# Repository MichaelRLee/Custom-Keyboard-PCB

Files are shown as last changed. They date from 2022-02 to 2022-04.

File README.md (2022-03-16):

# Lee Keyboard PCBs

Open source, hot-swappable board PCBs designed to be controlled by commonly available microcontroller boards (Pro Micro for the numpad, and Teensy LC, 3.2, etc. for the TKL).  These could easily be swapped out for any other board, but the qmk firmware would need to be modified for the specific controller.

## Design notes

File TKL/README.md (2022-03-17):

# tenleeless

tenleeless

<table>
<th colspan=2 style="text-align:center">Firmware</th>
<tr>
<td><a href="https://github.com/MichaelRLee/qmk_firmware/tree/tenkeyless/keyboards/finz/tenleeless">QMK</a></td>
<td><a href="">Vial</a></td>
</tr>
</table>

A hotswappable tenkeyless board, designed  with using a Teensy 3.2 as the controller.  Other controller boards with the same pinout (like the Teensy LC), should be usable, or any board with enough pins if not using pin headers (though adjustments to the QMK firmware would be needed).

### Design notes

The gap between the function keys and the alphanumeric cluster, as well as between the cluster and the nav keys, is 0.25u.  The spacebar stabalizer is the only one that has been flipped (wire north of the switch).  Any non-tray mounted mounting plate that fits the above should work with this PCB, though it was designed using a kbd8x plate as reference.

The board was is limted to a 7u space bar (1.5u ctrl/alt keys and 1u win keys, no fn/menu key), as well as a stepped caps lock.

As the microcontroller is located above the left arrow key, you may want to use a daughterboard (or female USB port).

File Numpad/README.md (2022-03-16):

# leepad

leepad

<table>
<th colspan=2 style="text-align:center">Firmware</th>
<tr>
<td><a href="https://github.com/MichaelRLee/qmk_firmware/tree/numpad/keyboards/finz/leepad">QMK</a></td>
<td><a href="https://github.com/MichaelRLee/vial-qmk/tree/numpad/keyboards/finz/leepad">Vial</a></td>
</tr>
</table>

A hotswappable numpad with extra macro keys.  Designed with the intention of using a Pro Micro as the controller, though the the spacing between the two PTH collumns do not reflect this.  What that means is that wires will have to be used in place of at least one row of pin headers.  The rational for this is to allow flexibility when mounting the Pro Micro (left or right side, or relocate the Pro Micro entirely).

Files (kicad and gerber) for a mounting plate are also included, which can easily be manufactured at the same time as the PCB.  For reference, the spacing between the macro keys and the rest of the keybaord is 0.25u, and all stabalizers have the wires facing inwards.

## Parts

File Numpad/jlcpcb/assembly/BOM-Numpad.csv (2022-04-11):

Comment | Designator | Footprint | LCSC
R_Small | R1 | R_Axial_DIN0207_L6.3mm_D2.5mm_P10.16mm_Horizontal
1N4148 | D16 | D_DO-34_SOD68_P7.62mm_Horizontal
1N4148 | D13 | D_DO-34_SOD68_P7.62mm_Horizontal
1N4148 | D8 | D_DO-34_SOD68_P7.62mm_Horizontal
1N4148 | D18 | D_DO-34_SOD68_P7.62mm_Horizontal
1N4148 | D17 | D_DO-34_SOD68_P7.62mm_Horizontal
1N4148 | D10 | D_DO-34_SOD68_P7.62mm_Horizontal
1N4148 | D5 | D_DO-34_SOD68_P7.62mm_Horizontal
1N4148 | D2 | D_DO-34_SOD68_P7.62mm_Horizontal
1N4148 | D3 | D_DO-34_SOD68_P7.62mm_Horizontal
1N4148 | D11 | D_DO-34_SOD68_P7.62mm_Horizontal
1N4148 | D15 | D_DO-34_SOD68_P7.62mm_Horizontal
1N4148 | D4 | D_DO-34_SOD68_P7.62mm_Horizontal
1N4148 | D19 | D_DO-34_SOD68_P7.62mm_Horizontal
1N4148 | D21 | D_DO-34_SOD68_P7.62mm_Horizontal
1N4148 | D6 | D_DO-34_SOD68_P7.62mm_Horizontal
1N4148 | D20 | D_DO-34_SOD68_P7.62mm_Horizontal
1N4148 | D12 | D_DO-34_SOD68_P7.62mm_Horizontal
1N4148 | D1 | D_DO-34_SOD68_P7.62mm_Horizontal
1N4148 | D9 | D_DO-34_SOD68_P7.62mm_Horizontal
1N4148 | D14 | D_DO-34_SOD68_P7.62mm_Horizontal
1N4148 | D7 | D_DO-34_SOD68_P7.62mm_Horizontal

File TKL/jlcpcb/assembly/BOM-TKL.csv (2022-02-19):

Comment | Designator | Footprint | LCSC
Tab | MX33 | MXOnly-1.5U-Hotswap-Antishear
; | MX59 | MXOnly-1U-Hotswap-Antishear
R_Alt | MX81 | MXOnly-1.5U-Hotswap-Antishear
v | MX68 | MXOnly-1U-Hotswap-Antishear
Insert | MX31 | MXOnly-1U-Hotswap-Antishear
m | MX71 | MXOnly-1U-Hotswap-Antishear
F10 | MX11 | MXOnly-1U-Hotswap-Antishear
Page Down | MX76 | MXOnly-1U-Hotswap-Antishear
F5 | MX6 | MXOnly-1U-Hotswap-Antishear
Enter | MX61 | MXOnly-2.25U-Hotswap-Antishear
r | MX37 | MXOnly-1U-Hotswap-Antishear
x | MX66 | MXOnly-1U-Hotswap-Antishear
, | MX72 | MXOnly-1U-Hotswap-Antishear
L_Alt | MX79 | MXOnly-1.5U-Hotswap-Antishear
9 | MX26 | MXOnly-1U-Hotswap-Antishear
5 | MX22 | MXOnly-1U-Hotswap-Antishear
L_Shift | MX64 | MXOnly-2.25U-Hotswap-Antishear
- | MX28 | MXOnly-1U-Hotswap-Antishear
0 | MX27 | MXOnly-1U-Hotswap-Antishear
= | MX29 | MXOnly-1U-Hotswap-Antishear
z | MX65 | MXOnly-1U-Hotswap-Antishear
g | MX54 | MXOnly-1U-Hotswap-Antishear
o | MX42 | MXOnly-1U-Hotswap-Antishear
Pause | MX16 | MXOnly-1U-Hotswap-Antishear
F4 | MX5 | MXOnly-1U-Hotswap-Antishear
7 | MX24 | MXOnly-1U-Hotswap-Antishear
j | MX56 | MXOnly-1U-Hotswap-Antishear
F11 | MX12 | MXOnly-1U-Hotswap-Antishear
Backspace | MX30 | MXOnly-2U-Hotswap-Antishear
h | MX55 | MXOnly-1U-Hotswap-Antishear
. | MX73 | MXOnly-1U-Hotswap-Antishear
End | MX48 | MXOnly-1U-Hotswap-Antishear
Print Screen | MX14 | MXOnly-1U-Hotswap-Antishear
q | MX34 | MXOnly-1U-Hotswap-Antishear
3 | MX20 | MXOnly-1U-Hotswap-Antishear
p | MX43 | MXOnly-1U-Hotswap-Antishear
c | MX67 | MXOnly-1U-Hotswap-Antishear
n | MX70 | MXOnly-1U-Hotswap-Antishear
F8 | MX9 | MXOnly-1U-Hotswap-Antishear
] | MX45 | MXOnly-1U-Hotswap-Antishear
Page Up | MX32 | MXOnly-1U-Hotswap-Antishear
y | MX39 | MXOnly-1U-Hotswap-Antishear
F2 | MX3 | MXOnly-1U-Hotswap-Antishear
i | MX41 | MXOnly-1U-Hotswap-Antishear
a | MX50 | MXOnly-1U-Hotswap-Antishear
F1 | MX2 | MXOnly-1U-Hotswap-Antishear
\ | MX46 | MXOnly-1.5U-Hotswap-Antishear
Teensy3.2 | U1 | Teensy30_31_32_LC
L_Ctrl | MX77 | MXOnly-1.5U-Hotswap-Antishear
2 | MX19 | MXOnly-1U-Hotswap-Antishear
L_Win | MX78 | MXOnly-1U-Hotswap-Antishear
Scroll Lock | MX15 | MXOnly-1U-Hotswap-Antishear-LED
[ | MX44 | MXOnly-1U-Hotswap-Antishear
R_Shift | MX75 | MXOnly-2.75U-Hotswap-Antishear
Down | MX85 | MXOnly-1U-Hotswap-Antishear
F6 | MX7 | MXOnly-1U-Hotswap-Antishear
' | MX60 | MXOnly-1U-Hotswap-Antishear
u | MX40 | MXOnly-1U-Hotswap-Antishear
Left | MX84 | MXOnly-1U-Hotswap-Antishear
4 | MX21 | MXOnly-1U-Hotswap-Antishear
Space | MX80 | MXOnly-7U-Hotswap-Antishear-ReversedStabilizers
Caps Lock | MX49 | MXOnly-1U-Hotswap-Antishear-LED
F3 | MX4 | MXOnly-1U-Hotswap-Antishear
Esc | MX1 | MXOnly-1U-Hotswap-Antishear
6 | MX23 | MXOnly-1U-Hotswap-Antishear
F12 | MX13 | MXOnly-1U-Hotswap-Antishear
t | MX38 | MXOnly-1U-Hotswap-Antishear
Home | MX63 | MXOnly-1U-Hotswap-Antishear
R_Ctrl | MX83 | MXOnly-1.5U-Hotswap-Antishear
F7 | MX8 | MXOnly-1U-Hotswap-Antishear
Delete | MX47 | MXOnly-1U-Hotswap-Antishear
k | MX57 | MXOnly-1U-Hotswap-Antishear
R_Win | MX82 | MXOnly-1U-Hotswap-Antishear
F9 | MX10 | MXOnly-1U-Hotswap-Antishear
Up | MX62 | MXOnly-1U-Hotswap-Antishear
e | MX36 | MXOnly-1U-Hotswap-Antishear
d | MX52 | MXOnly-1U-Hotswap-Antishear
8 | MX25 | MXOnly-1U-Hotswap-Antishear
w | MX35 | MXOnly-1U-Hotswap-Antishear
` | MX17 | MXOnly-1U-Hotswap-Antishear
b | MX69 | MXOnly-1U-Hotswap-Antishear
Right | MX86 | MXOnly-1U-Hotswap-Antishear
/ | MX74 | MXOnly-1U-Hotswap-Antishear
1 | MX18 | MXOnly-1U-Hotswap-Antishear
l | MX58 | MXOnly-1U-Hotswap-Antishear
s | MX51 | MXOnly-1U-Hotswap-Antishear
f | MX53 | MXOnly-1U-Hotswap-Antishear
1N4148 | D39 | D_DO-35_SOD27_P7.62mm_Horizontal
1N4148 | D36 | D_DO-35_SOD27_P7.62mm_Horizontal
1N4148 | D24 | D_DO-35_SOD27_P7.62mm_Horizontal
1N4148 | D73 | D_DO-35_SOD27_P7.62mm_Horizontal
1N4148 | D41 | D_DO-35_SOD27_P7.62mm_Horizontal
1N4148 | D7 | D_DO-35_SOD27_P7.62mm_Horizontal
1N4148 | D28 | D_DO-35_SOD27_P7.62mm_Horizontal
1N4148 | D57 | D_DO-35_SOD27_P7.62mm_Horizontal
1N4148 | D21 | D_DO-35_SOD27_P7.62mm_Horizontal
1N4148 | D75 | D_DO-35_SOD27_P7.62mm_Horizontal
1N4148 | D72 | D_DO-35_SOD27_P7.62mm_Horizontal
1N4148 | D37 | D_DO-35_SOD27_P7.62mm_Horizontal
1N4148 | D60 | D_DO-35_SOD27_P7.62mm_Horizontal
1N4148 | D27 | D_DO-35_SOD27_P7.62mm_Horizontal
1N4148 | D77 | D_DO-35_SOD27_P7.62mm_Horizontal
1N4148 | D5 | D_DO-35_SOD27_P7.62mm_Horizontal
1N4148 | D46 | D_DO-35_SOD27_P7.62mm_Horizontal
1N4148 | D86 | D_DO-35_SOD27_P7.62mm_Horizontal
1N4148 | D64 | D_DO-35_SOD27_P7.62mm_Horizontal
1N4148 | D44 | D_DO-35_SOD27_P7.62mm_Horizontal
1N4148 | D59 | D_DO-35_SOD27_P7.62mm_Horizontal
1N4148 | D1 | D_DO-35_SOD27_P7.62mm_Horizontal
1N4148 | D30 | D_DO-35_SOD27_P7.62mm_Horizontal
1N4148 | D61 | D_DO-35_SOD27_P7.62mm_Horizontal
1N4148 | D19 | D_DO-35_SOD27_P7.62mm_Horizontal
1N4148 | D25 | D_DO-35_SOD27_P7.62mm_Horizontal
1N4148 | D3 | D_DO-35_SOD27_P7.62mm_Horizontal
1N4148 | D49 | D_DO-35_SOD27_P7.62mm_Horizontal
1N4148 | D81 | D_DO-35_SOD27_P7.62mm_Horizontal
1N4148 | D14 | D_DO-35_SOD27_P7.62mm_Horizontal
1N4148 | D63 | D_DO-35_SOD27_P7.62mm_Horizontal
1N4148 | D78 | D_DO-35_SOD27_P7.62mm_Horizontal
1N4148 | D9 | D_DO-35_SOD27_P7.62mm_Horizontal
1N4148 | D79 | D_DO-35_SOD27_P7.62mm_Horizontal
1N4148 | D12 | D_DO-35_SOD27_P7.62mm_Horizontal
1N4148 | D43 | D_DO-35_SOD27_P7.62mm_Horizontal
1N4148 | D82 | D_DO-35_SOD27_P7.62mm_Horizontal
1N4148 | D48 | D_DO-35_SOD27_P7.62mm_Horizontal
1N4148 | D53 | D_DO-35_SOD27_P7.62mm_Horizontal
1N4148 | D40 | D_DO-35_SOD27_P7.62mm_Horizontal
1N4148 | D31 | D_DO-35_SOD27_P7.62mm_Horizontal
1N4148 | D35 | D_DO-35_SOD27_P7.62mm_Horizontal
1N4148 | D45 | D_DO-35_SOD27_P7.62mm_Horizontal
1N4148 | D68 | D_DO-35_SOD27_P7.62mm_Horizontal
1N4148 | D29 | D_DO-35_SOD27_P7.62mm_Horizontal
1N4148 | D54 | D_DO-35_SOD27_P7.62mm_Horizontal
1N4148 | D65 | D_DO-35_SOD27_P7.62mm_Horizontal
1N4148 | D33 | D_DO-35_SOD27_P7.62mm_Horizontal
1N4148 | D51 | D_DO-35_SOD27_P7.62mm_Horizontal
1N4148 | D70 | D_DO-35_SOD27_P7.62mm_Horizontal
1N4148 | D11 | D_DO-35_SOD27_P7.62mm_Horizontal
1N4148 | D6 | D_DO-35_SOD27_P7.62mm_Horizontal
1N4148 | D69 | D_DO-35_SOD27_P7.62mm_Horizontal
1N4148 | D52 | D_DO-35_SOD27_P7.62mm_Horizontal
1N4148 | D67 | D_DO-35_SOD27_P7.62mm_Horizontal
1N4148 | D32 | D_DO-35_SOD27_P7.62mm_Horizontal
1N4148 | D18 | D_DO-35_SOD27_P7.62mm_Horizontal
1N4148 | D34 | D_DO-35_SOD27_P7.62mm_Horizontal
1N4148 | D47 | D_DO-35_SOD27_P7.62mm_Horizontal
1N4148 | D62 | D_DO-35_SOD27_P7.62mm_Horizontal
1N4148 | D16 | D_DO-35_SOD27_P7.62mm_Horizontal
1N4148 | D85 | D_DO-35_SOD27_P7.62mm_Horizontal
1N4148 | D15 | D_DO-35_SOD27_P7.62mm_Horizontal
1N4148 | D20 | D_DO-35_SOD27_P7.62mm_Horizontal
1N4148 | D83 | D_DO-35_SOD27_P7.62mm_Horizontal
1N4148 | D10 | D_DO-35_SOD27_P7.62mm_Horizontal
1N4148 | D76 | D_DO-35_SOD27_P7.62mm_Horizontal
1N4148 | D50 | D_DO-35_SOD27_P7.62mm_Horizontal
R_Small | R1 | R_Axial_DIN0207_L6.3mm_D2.5mm_P7.62mm_Horizontal
1N4148 | D58 | D_DO-35_SOD27_P7.62mm_Horizontal
1N4148 | D13 | D_DO-35_SOD27_P7.62mm_Horizontal
1N4148 | D80 | D_DO-35_SOD27_P7.62mm_Horizontal
1N4148 | D4 | D_DO-35_SOD27_P7.62mm_Horizontal
1N4148 | D8 | D_DO-35_SOD27_P7.62mm_Horizontal
1N4148 | D55 | D_DO-35_SOD27_P7.62mm_Horizontal
1N4148 | D38 | D_DO-35_SOD27_P7.62mm_Horizontal
1N4148 | D56 | D_DO-35_SOD27_P7.62mm_Horizontal
1N4148 | D42 | D_DO-35_SOD27_P7.62mm_Horizontal
1N4148 | D2 | D_DO-35_SOD27_P7.62mm_Horizontal
1N4148 | D74 | D_DO-35_SOD27_P7.62mm_Horizontal
1N4148 | D84 | D_DO-35_SOD27_P7.62mm_Horizontal
R_Small | R2 | R_Axial_DIN0207_L6.3mm_D2.5mm_P7.62mm_Horizontal
1N4148 | D66 | D_DO-35_SOD27_P7.62mm_Horizontal
1N4148 | D17 | D_DO-35_SOD27_P7.62mm_Horizontal
1N4148 | D22 | D_DO-35_SOD27_P7.62mm_Horizontal
1N4148 | D26 | D_DO-35_SOD27_P7.62mm_Horizontal
1N4148 | D71 | D_DO-35_SOD27_P7.62mm_Horizontal
1N4148 | D23 | D_DO-35_SOD27_P7.62mm_Horizontal

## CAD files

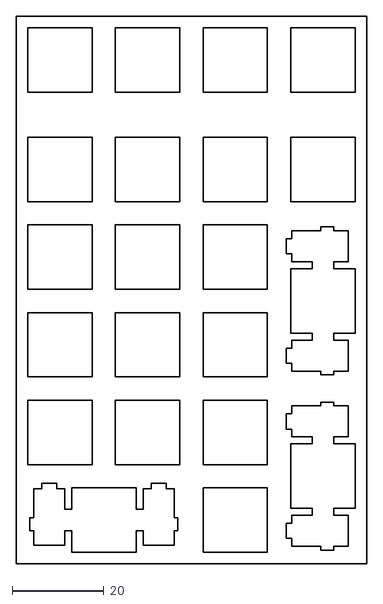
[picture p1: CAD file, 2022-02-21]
Numpad/plate/numpad-plate.dxf
76.2 x 119.1

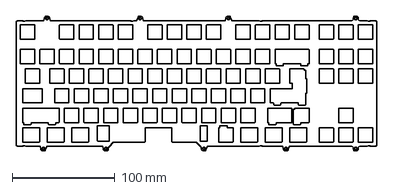
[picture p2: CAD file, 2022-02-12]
TKL/KBD8X-MKII-Plate-Simplified.dxf
350.6 x 130.7 mm

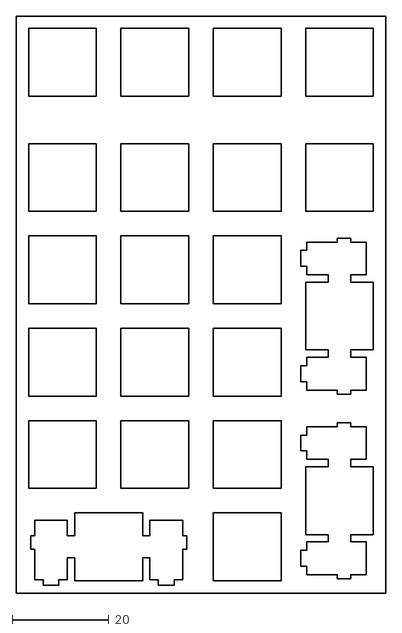
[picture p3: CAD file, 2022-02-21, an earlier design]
Numpad/plate/numpad-plate-old.dxf
76.2 x 119.1

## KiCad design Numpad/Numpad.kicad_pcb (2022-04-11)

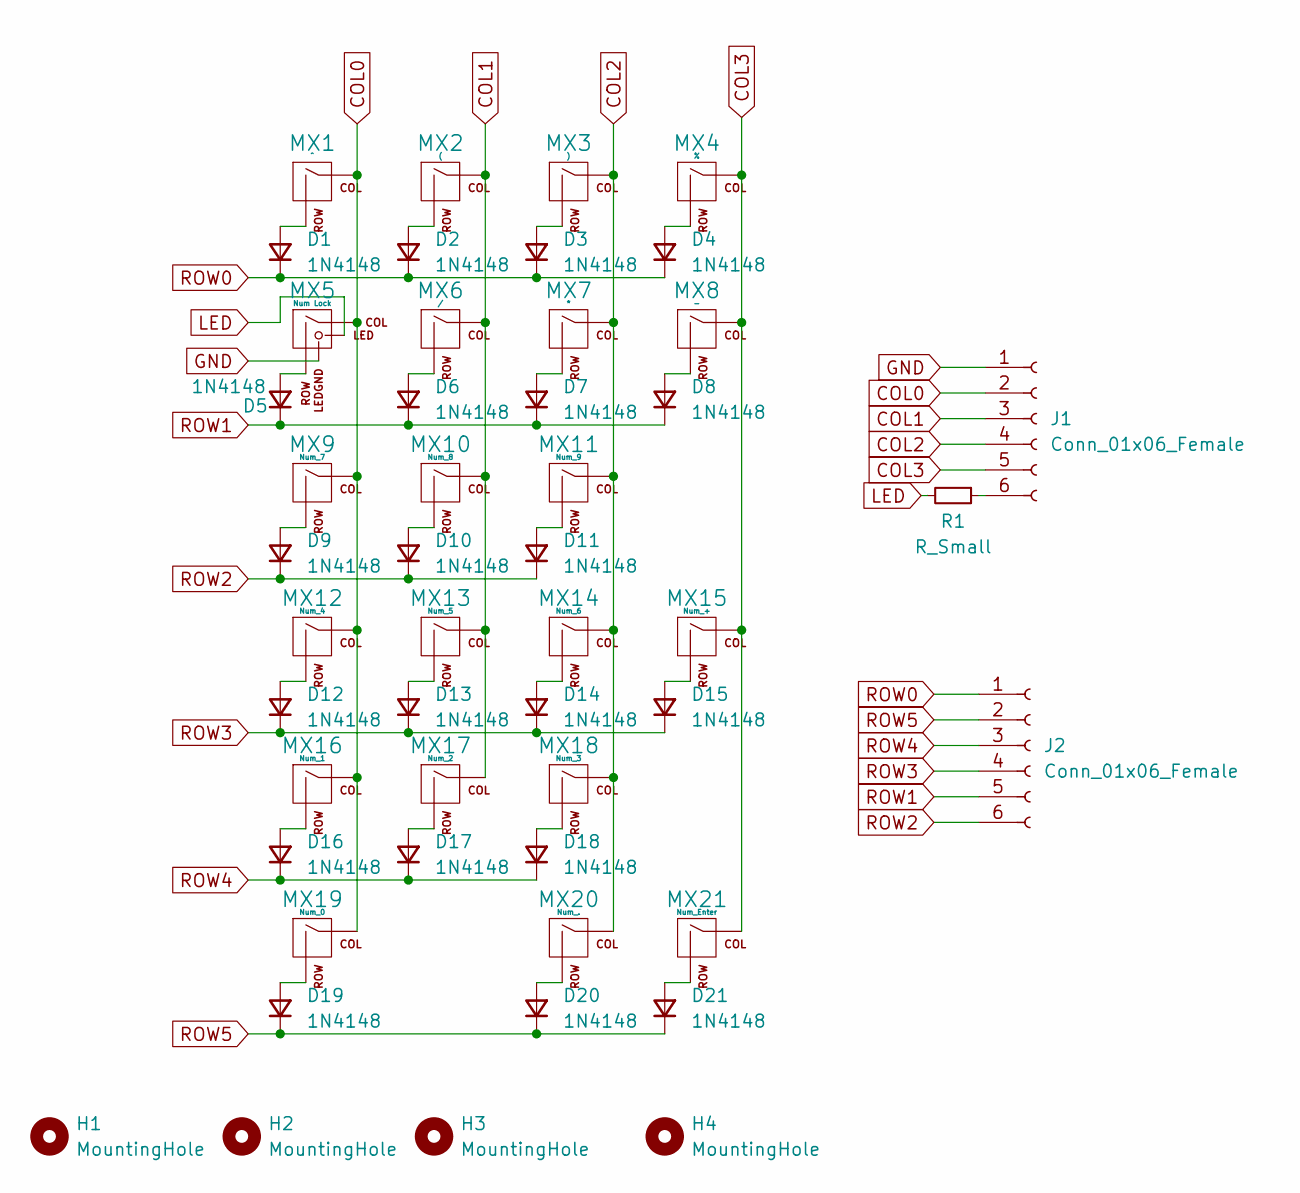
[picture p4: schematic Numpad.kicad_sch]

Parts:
D1, D2, D3, D4, D5, D6, D7, D8, D9, D10, D11, D12, D13, D14, D15, D16, D17, D18, D19, D20, D21: 1N4148; D_DO-34_SOD68_P7.62mm_Horizontal
H1, H2, H3, H4: MountingHole; MountingHole_2.2mm_M2_Pad
J1, J2: Conn_01x06_Female; PinHeader_1x06_P2.54mm_Vertical
MX1: ^; MXOnly-1U-Hotswap-Antishear
MX2: (; MXOnly-1U-Hotswap-Antishear
MX3: ); MXOnly-1U-Hotswap-Antishear
MX4: %; MXOnly-1U-Hotswap-Antishear
MX5: Num Lock; MXOnly-1U-Hotswap-Antishear-LED
MX6: /; MXOnly-1U-Hotswap-Antishear
MX7: *; MXOnly-1U-Hotswap-Antishear
MX8: -; MXOnly-1U-Hotswap-Antishear
MX9: Num_7; MXOnly-1U-Hotswap-Antishear
MX10: Num_8; MXOnly-1U-Hotswap-Antishear
MX11: Num_9; MXOnly-1U-Hotswap-Antishear
MX12: Num_4; MXOnly-1U-Hotswap-Antishear
MX13: Num_5; MXOnly-1U-Hotswap-Antishear
MX14: Num_6; MXOnly-1U-Hotswap-Antishear
MX15: Num_+; MXOnly-2U-Hotswap-Antishear-ReversedVerticalStabilizers
MX16: Num_1; MXOnly-1U-Hotswap-Antishear
MX17: Num_2; MXOnly-1U-Hotswap-Antishear
MX18: Num_3; MXOnly-1U-Hotswap-Antishear
MX19: Num_0; MXOnly-2U-Hotswap-Antishear-ReversedStabilizers
MX20: Num_.; MXOnly-1U-Hotswap-Antishear
MX21: Num_Enter; MXOnly-2U-Hotswap-Antishear-ReversedVerticalStabilizers
R1: R_Small; R_Axial_DIN0207_L6.3mm_D2.5mm_P10.16mm_Horizontal

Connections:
COL0: J1.2, MX1.1 (COL), MX5.1 (COL), MX9.1 (COL), MX12.1 (COL), MX16.1 (COL), MX19.1 (COL)
COL1: J1.3, MX2.1 (COL), MX6.1 (COL), MX10.1 (COL), MX13.1 (COL), MX17.1 (COL)
COL2: J1.4, MX3.1 (COL), MX7.1 (COL), MX11.1 (COL), MX14.1 (COL), MX18.1 (COL), MX20.1 (COL)
COL3: J1.5, MX4.1 (COL), MX8.1 (COL), MX15.1 (COL), MX21.1 (COL)
GND: J1.1, MX5.4 (LEDGND)
LED: MX5.3 (LED), R1.2
unnamed: D1.2 (A), MX1.2 (ROW)
unnamed: D2.2 (A), MX2.2 (ROW)
unnamed: D3.2 (A), MX3.2 (ROW)
unnamed: D4.2 (A), MX4.2 (ROW)
unnamed: D5.2 (A), MX5.2 (ROW)
unnamed: D6.2 (A), MX6.2 (ROW)
unnamed: D7.2 (A), MX7.2 (ROW)
unnamed: D8.2 (A), MX8.2 (ROW)
unnamed: D9.2 (A), MX9.2 (ROW)
unnamed: D10.2 (A), MX10.2 (ROW)
unnamed: D11.2 (A), MX11.2 (ROW)
unnamed: D12.2 (A), MX12.2 (ROW)
unnamed: D13.2 (A), MX13.2 (ROW)
unnamed: D14.2 (A), MX14.2 (ROW)
unnamed: D15.2 (A), MX15.2 (ROW)
unnamed: D16.2 (A), MX16.2 (ROW)
unnamed: D17.2 (A), MX17.2 (ROW)
unnamed: D18.2 (A), MX18.2 (ROW)
unnamed: D19.2 (A), MX19.2 (ROW)
unnamed: D20.2 (A), MX20.2 (ROW)
unnamed: D21.2 (A), MX21.2 (ROW)
unnamed: J1.6, R1.1
ROW0: D1.1 (K), D2.1 (K), D3.1 (K), D4.1 (K), J2.1
ROW1: D5.1 (K), D6.1 (K), D7.1 (K), D8.1 (K), J2.5
ROW2: D9.1 (K), D10.1 (K), D11.1 (K), J2.6
ROW3: D12.1 (K), D13.1 (K), D14.1 (K), D15.1 (K), J2.4
ROW4: D16.1 (K), D17.1 (K), D18.1 (K), J2.3
ROW5: D19.1 (K), D20.1 (K), D21.1 (K), J2.2

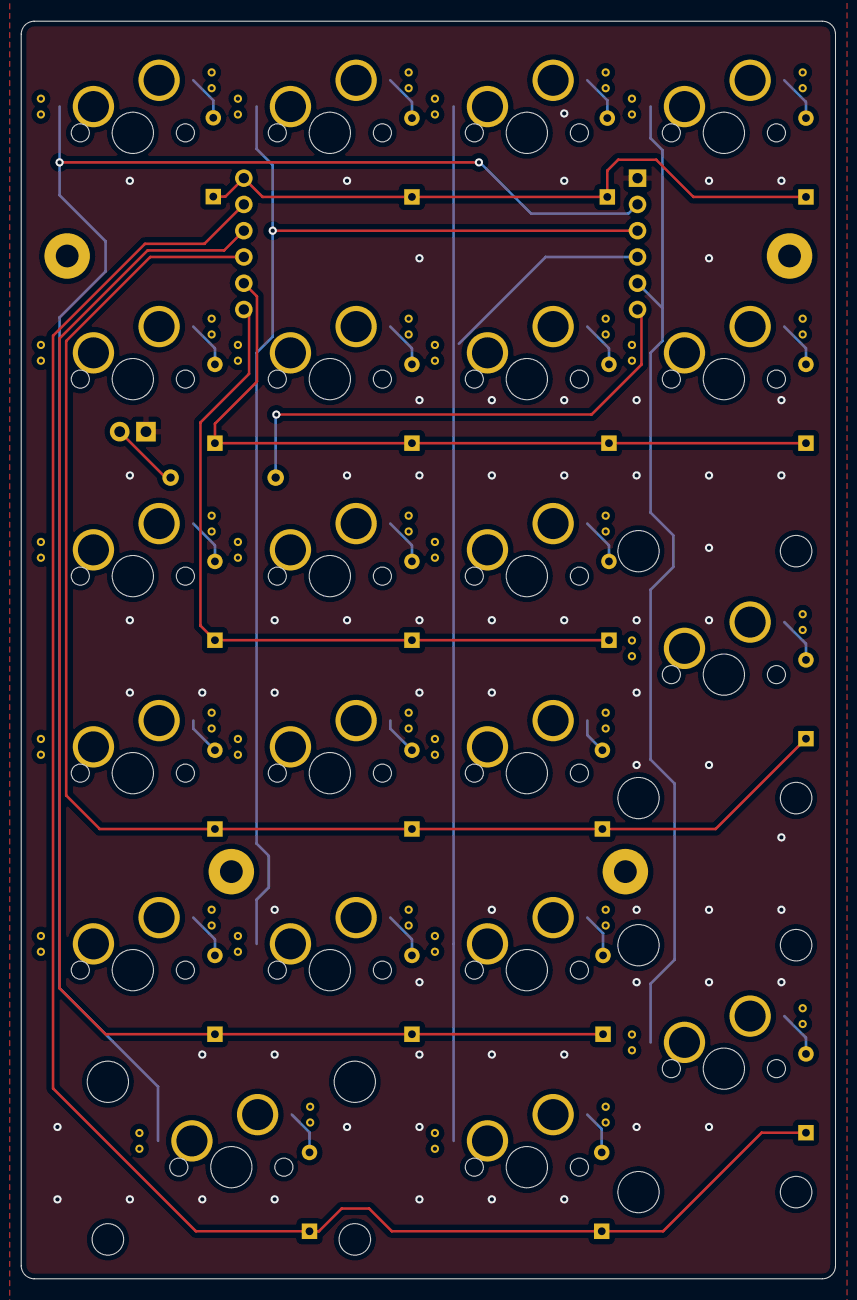
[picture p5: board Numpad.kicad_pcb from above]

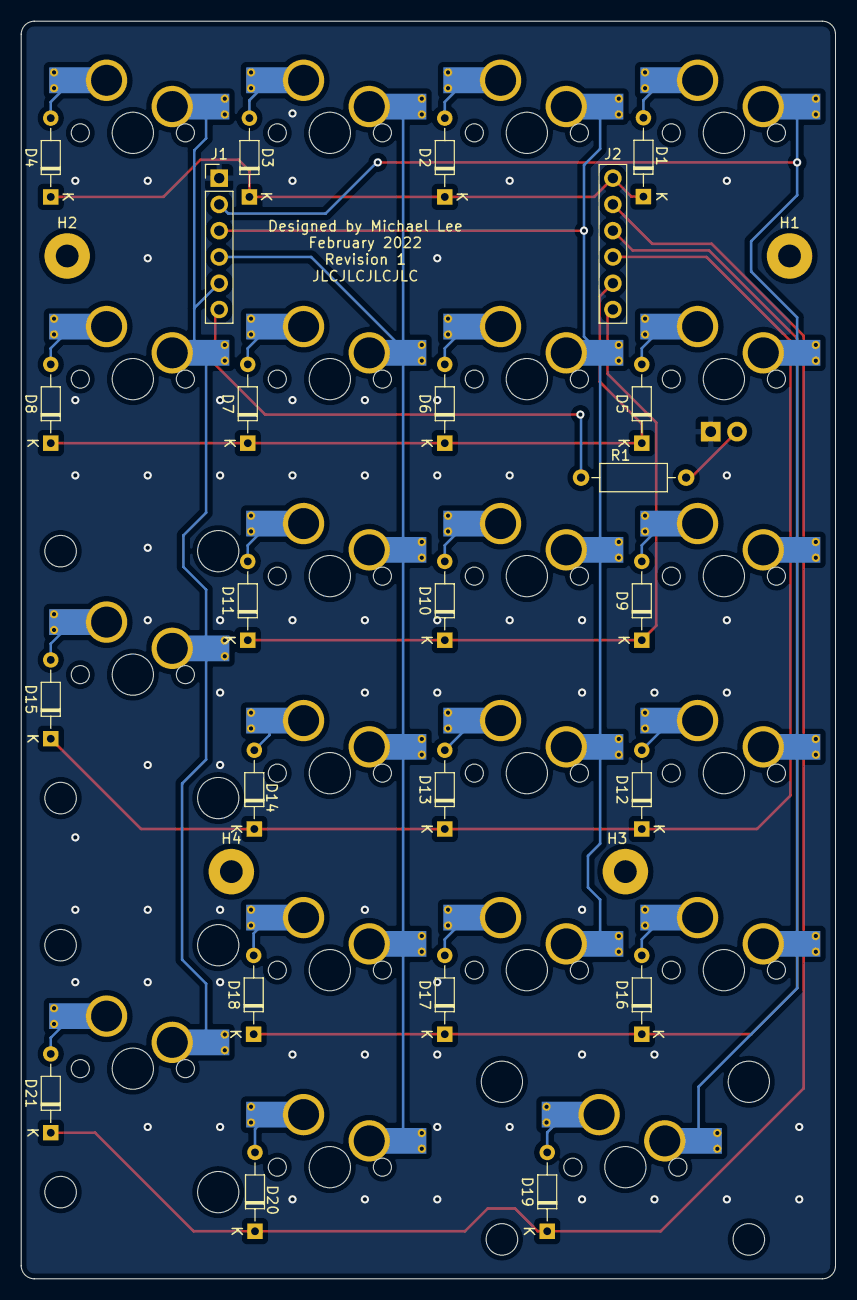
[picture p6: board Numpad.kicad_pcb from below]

Board: 2 copper layers, 78.7 x 121.6 mm, 49 parts (28 on the bottom side), 34 nets.

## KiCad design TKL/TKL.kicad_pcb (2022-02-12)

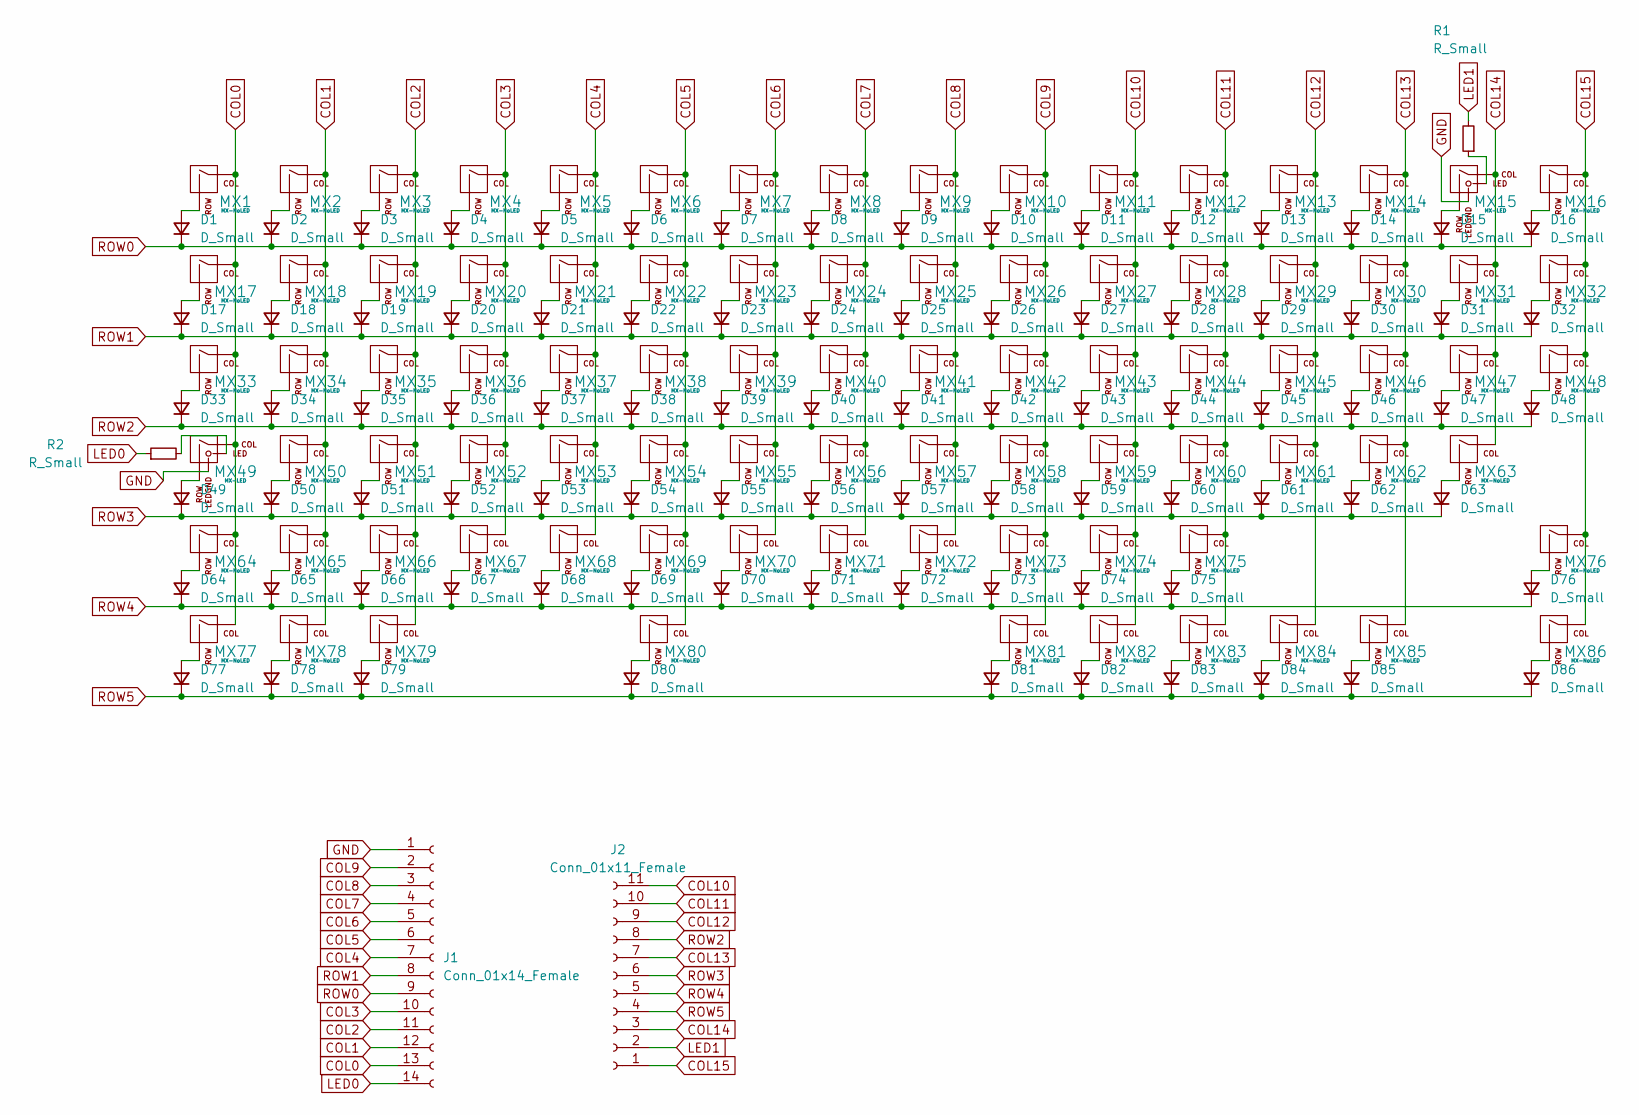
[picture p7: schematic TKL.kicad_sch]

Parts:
D1, D2, D3, D4, D5, D6, D7, D8, D9, D10, D11, D12, D13, D14, D15, D16, D17, D18, D19, D20, D21, D22, D23, D24, D25, D26, D27, D28, D29, D30, D31, D32, D33, D34, D35, D36, D37, D38, D39, D40, D41, D42, D43, D44, D45, D46, D47, D48, D49, D50, D51, D52, D53, D54, D55, D56, D57, D58, D59, D60, D61, D62, D63, D64, D65, D66, D67, D68, D69, D70, D71, D72, D73, D74, D75, D76, D77, D78, D79, D80, D81, D82, D83, D84, D85, D86: D_Small; D_DO-35_SOD27_P7.62mm_Horizontal
J1: Conn_01x14_Female; PinHeader_1x14_P2.54mm_Vertical
J2: Conn_01x11_Female; PinHeader_1x11_P2.54mm_Vertical
MX1, MX2, MX3, MX4, MX5, MX6, MX7, MX8, MX9, MX10, MX11, MX12, MX13, MX14, MX16, MX18, MX19, MX20, MX21, MX22, MX23, MX24, MX25, MX26, MX27, MX28, MX29, MX31, MX32, MX34, MX35, MX36, MX37, MX38, MX39, MX40, MX41, MX42, MX43, MX44, MX45, MX47, MX48, MX50, MX51, MX52, MX53, MX54, MX55, MX56, MX57, MX58, MX59, MX60, MX62, MX63, MX65, MX66, MX67, MX68, MX69, MX70, MX71, MX72, MX73, MX74, MX76, MX78, MX82, MX84, MX85, MX86: MX-NoLED; MXOnly-1U-Hotswap-Antishear
MX15: MX-LED; MXOnly-1U-Hotswap-Antishear-LED
MX17: MX-NoLED; MXOnly-1U-Hotswap
MX30: MX-NoLED; MXOnly-2U-Hotswap-Antishear
MX33, MX46, MX77, MX79, MX81, MX83: MX-NoLED; MXOnly-1.5U-Hotswap-Antishear
MX49: MX-LED; MXOnly-Caps-Hotswap-Antishear-LED
MX61, MX64: MX-NoLED; MXOnly-2.25U-Hotswap-Antishear
MX75: MX-NoLED; MXOnly-2.75U-Hotswap-Antishear
MX80: MX-NoLED; MXOnly-7U-Hotswap-Antishear
R1, R2: R_Small; R_Axial_DIN0207_L6.3mm_D2.5mm_P7.62mm_Horizontal

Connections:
COL0: J1.13, MX1.1 (COL), MX17.1 (COL), MX33.1 (COL), MX49.1 (COL), MX64.1 (COL), MX77.1 (COL)
COL1: J1.12, MX2.1 (COL), MX18.1 (COL), MX34.1 (COL), MX50.1 (COL), MX65.1 (COL), MX78.1 (COL)
COL2: J1.11, MX3.1 (COL), MX19.1 (COL), MX35.1 (COL), MX51.1 (COL), MX66.1 (COL), MX79.1 (COL)
COL3: J1.10, MX4.1 (COL), MX20.1 (COL), MX36.1 (COL), MX52.1 (COL), MX67.1 (COL)
COL4: J1.7, MX5.1 (COL), MX21.1 (COL), MX37.1 (COL), MX53.1 (COL), MX68.1 (COL)
COL5: J1.6, MX6.1 (COL), MX22.1 (COL), MX38.1 (COL), MX54.1 (COL), MX69.1 (COL), MX80.1 (COL)
COL6: J1.5, MX7.1 (COL), MX23.1 (COL), MX39.1 (COL), MX55.1 (COL), MX70.1 (COL)
COL7: J1.4, MX8.1 (COL), MX24.1 (COL), MX40.1 (COL), MX56.1 (COL), MX71.1 (COL)
COL8: J1.3, MX9.1 (COL), MX25.1 (COL), MX41.1 (COL), MX57.1 (COL), MX72.1 (COL)
COL9: J1.2, MX10.1 (COL), MX26.1 (COL), MX42.1 (COL), MX58.1 (COL), MX73.1 (COL), MX81.1 (COL)
COL10: J2.11, MX11.1 (COL), MX27.1 (COL), MX43.1 (COL), MX59.1 (COL), MX74.1 (COL), MX82.1 (COL)
COL11: J2.10, MX12.1 (COL), MX28.1 (COL), MX44.1 (COL), MX60.1 (COL), MX75.1 (COL), MX83.1 (COL)
COL12: J2.9, MX13.1 (COL), MX29.1 (COL), MX45.1 (COL), MX61.1 (COL), MX84.1 (COL)
COL13: J2.7, MX14.1 (COL), MX30.1 (COL), MX46.1 (COL), MX62.1 (COL), MX85.1 (COL)
COL14: J2.3, MX15.1 (COL), MX31.1 (COL), MX47.1 (COL), MX63.1 (COL)
COL15: J2.1, MX16.1 (COL), MX32.1 (COL), MX48.1 (COL), MX76.1 (COL), MX86.1 (COL)
GND: J1.1, MX15.4 (LEDGND), MX49.4 (LEDGND)
LED0: J1.14, R2.1
LED1: J2.2, R1.2
unnamed: D1.2 (A), MX1.2 (ROW)
unnamed: D2.2 (A), MX2.2 (ROW)
unnamed: D3.2 (A), MX3.2 (ROW)
unnamed: D4.2 (A), MX4.2 (ROW)
unnamed: D5.2 (A), MX5.2 (ROW)
unnamed: D6.2 (A), MX6.2 (ROW)
unnamed: D7.2 (A), MX7.2 (ROW)
unnamed: D8.2 (A), MX8.2 (ROW)
unnamed: D9.2 (A), MX9.2 (ROW)
unnamed: D10.2 (A), MX10.2 (ROW)
unnamed: D11.2 (A), MX11.2 (ROW)
unnamed: D12.2 (A), MX12.2 (ROW)
unnamed: D13.2 (A), MX13.2 (ROW)
unnamed: D14.2 (A), MX14.2 (ROW)
unnamed: D15.2 (A), MX15.2 (ROW)
unnamed: D16.2 (A), MX16.2 (ROW)
unnamed: D17.2 (A), MX17.2 (ROW)
unnamed: D18.2 (A), MX18.2 (ROW)
unnamed: D19.2 (A), MX19.2 (ROW)
unnamed: D20.2 (A), MX20.2 (ROW)
unnamed: D21.2 (A), MX21.2 (ROW)
unnamed: D22.2 (A), MX22.2 (ROW)
unnamed: D23.2 (A), MX23.2 (ROW)
unnamed: D24.2 (A), MX24.2 (ROW)
unnamed: D25.2 (A), MX25.2 (ROW)
unnamed: D26.2 (A), MX26.2 (ROW)
unnamed: D27.2 (A), MX27.2 (ROW)
unnamed: D28.2 (A), MX28.2 (ROW)
unnamed: D29.2 (A), MX29.2 (ROW)
unnamed: D30.2 (A), MX30.2 (ROW)
unnamed: D31.2 (A), MX31.2 (ROW)
unnamed: D32.2 (A), MX32.2 (ROW)
unnamed: D33.2 (A), MX33.2 (ROW)
unnamed: D34.2 (A), MX34.2 (ROW)
unnamed: D35.2 (A), MX35.2 (ROW)
unnamed: D36.2 (A), MX36.2 (ROW)
unnamed: D37.2 (A), MX37.2 (ROW)
unnamed: D38.2 (A), MX38.2 (ROW)
unnamed: D39.2 (A), MX39.2 (ROW)
unnamed: D40.2 (A), MX40.2 (ROW)
unnamed: D41.2 (A), MX41.2 (ROW)
unnamed: D42.2 (A), MX42.2 (ROW)
unnamed: D43.2 (A), MX43.2 (ROW)
unnamed: D44.2 (A), MX44.2 (ROW)
unnamed: D45.2 (A), MX45.2 (ROW)
unnamed: D46.2 (A), MX46.2 (ROW)
unnamed: D47.2 (A), MX47.2 (ROW)
unnamed: D48.2 (A), MX48.2 (ROW)
unnamed: D49.2 (A), MX49.2 (ROW)
unnamed: D50.2 (A), MX50.2 (ROW)
unnamed: D51.2 (A), MX51.2 (ROW)
unnamed: D52.2 (A), MX52.2 (ROW)
unnamed: D53.2 (A), MX53.2 (ROW)
unnamed: D54.2 (A), MX54.2 (ROW)
unnamed: D55.2 (A), MX55.2 (ROW)
unnamed: D56.2 (A), MX56.2 (ROW)
unnamed: D57.2 (A), MX57.2 (ROW)
unnamed: D58.2 (A), MX58.2 (ROW)
unnamed: D59.2 (A), MX59.2 (ROW)
unnamed: D60.2 (A), MX60.2 (ROW)
unnamed: D61.2 (A), MX61.2 (ROW)
unnamed: D62.2 (A), MX62.2 (ROW)
unnamed: D63.2 (A), MX63.2 (ROW)
unnamed: D64.2 (A), MX64.2 (ROW)
unnamed: D65.2 (A), MX65.2 (ROW)
unnamed: D66.2 (A), MX66.2 (ROW)
unnamed: D67.2 (A), MX67.2 (ROW)
unnamed: D68.2 (A), MX68.2 (ROW)
unnamed: D69.2 (A), MX69.2 (ROW)
unnamed: D70.2 (A), MX70.2 (ROW)
unnamed: D71.2 (A), MX71.2 (ROW)
unnamed: D72.2 (A), MX72.2 (ROW)
unnamed: D73.2 (A), MX73.2 (ROW)
unnamed: D74.2 (A), MX74.2 (ROW)
unnamed: D75.2 (A), MX75.2 (ROW)
unnamed: D76.2 (A), MX76.2 (ROW)
unnamed: D77.2 (A), MX77.2 (ROW)
unnamed: D78.2 (A), MX78.2 (ROW)
unnamed: D79.2 (A), MX79.2 (ROW)
unnamed: D80.2 (A), MX80.2 (ROW)
unnamed: D81.2 (A), MX81.2 (ROW)
unnamed: D82.2 (A), MX82.2 (ROW)
unnamed: D83.2 (A), MX83.2 (ROW)
unnamed: D84.2 (A), MX84.2 (ROW)
unnamed: D85.2 (A), MX85.2 (ROW)
unnamed: D86.2 (A), MX86.2 (ROW)
unnamed: MX15.3 (LED), R1.1
unnamed: MX49.3 (LED), R2.2
ROW0: D1.1 (K), D2.1 (K), D3.1 (K), D4.1 (K), D5.1 (K), D6.1 (K), D7.1 (K), D8.1 (K), D9.1 (K), D10.1 (K), D11.1 (K), D12.1 (K), D13.1 (K), D14.1 (K), D15.1 (K), D16.1 (K), J1.9
ROW1: D17.1 (K), D18.1 (K), D19.1 (K), D20.1 (K), D21.1 (K), D22.1 (K), D23.1 (K), D24.1 (K), D25.1 (K), D26.1 (K), D27.1 (K), D28.1 (K), D29.1 (K), D30.1 (K), D31.1 (K), D32.1 (K), J1.8
ROW2: D33.1 (K), D34.1 (K), D35.1 (K), D36.1 (K), D37.1 (K), D38.1 (K), D39.1 (K), D40.1 (K), D41.1 (K), D42.1 (K), D43.1 (K), D44.1 (K), D45.1 (K), D46.1 (K), D47.1 (K), D48.1 (K), J2.8
ROW3: D49.1 (K), D50.1 (K), D51.1 (K), D52.1 (K), D53.1 (K), D54.1 (K), D55.1 (K), D56.1 (K), D57.1 (K), D58.1 (K), D59.1 (K), D60.1 (K), D61.1 (K), D62.1 (K), D63.1 (K), J2.6
ROW4: D64.1 (K), D65.1 (K), D66.1 (K), D67.1 (K), D68.1 (K), D69.1 (K), D70.1 (K), D71.1 (K), D72.1 (K), D73.1 (K), D74.1 (K), D75.1 (K), D76.1 (K), J2.5
ROW5: D77.1 (K), D78.1 (K), D79.1 (K), D80.1 (K), D81.1 (K), D82.1 (K), D83.1 (K), D84.1 (K), D85.1 (K), D86.1 (K), J2.4

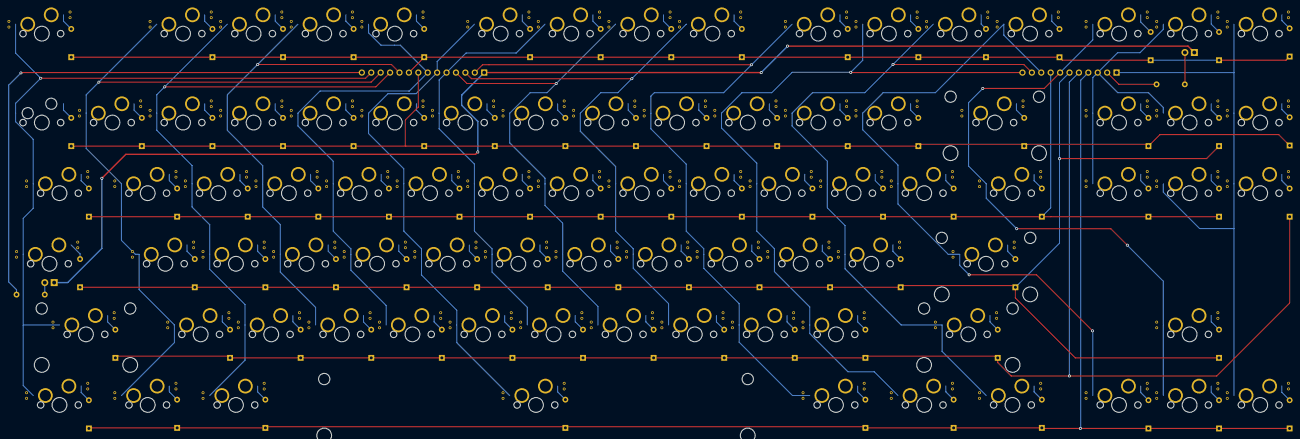
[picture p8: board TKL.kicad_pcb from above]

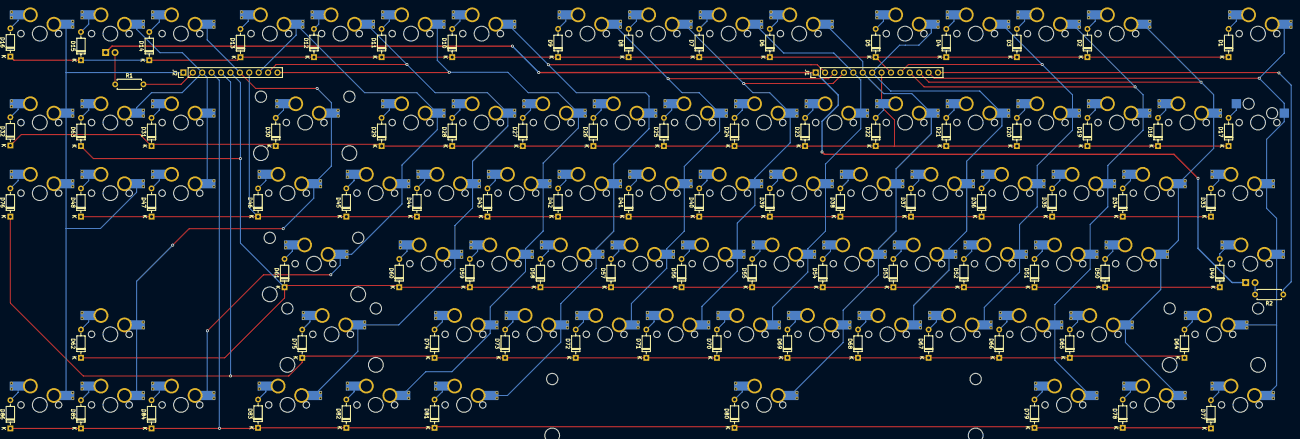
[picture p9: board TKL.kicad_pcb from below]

Board: 2 copper layers, 176 parts (90 on the bottom side), 113 nets.

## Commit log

2022-01-28 Submodule libraries added, TKL project initialized
    [TKL.kicad_pcb, TKL.kicad_sch]
2022-01-29 TKL matrix added
    [TKL.kicad_sch]
2022-01-29 Submodule added for teensy. Libraries updated
2022-02-12 Reworked schematic and pcb
    [TKL.kicad_pcb, TKL.kicad_sch]
2022-02-12 Completed PCB and fixed spacing
    [KBD8X-MKII-Plate-Simplified.dxf, TKL.kicad_sch]
2022-02-12 Added ground planes and KDB8x MKII screw holes
2022-02-14 Removed mounting holes, improved board aesthetics
    [TKL.kicad_sch]
2022-02-14 Added silkscreen and decoration
    [TKL.kicad_sch]
2022-02-14 Created numpad. Cleaned up repo
    [Numpad.kicad_pcb, Numpad.kicad_sch]
2022-02-14 Minor update
    [Numpad.kicad_pcb]
2022-02-14 Swapped header pins on numpad
    [Numpad.kicad_pcb, Numpad.kicad_sch]
2022-02-16 Set track width to 10 mils
    [Numpad.kicad_pcb]
2022-02-16 Changed traces on TKL to connect directly to teensy board
    [TKL.kicad_sch]
2022-02-17 Flipped orientation of Teensy and re-added via stitching
    [TKL.kicad_sch]
2022-02-17 Added mounting holes to numpad
    [Numpad.kicad_pcb, Numpad.kicad_sch]
2022-02-19 Reversed spacebar stab. Added jlcpcb gerber files
    [BOM-Numpad.csv, BOM-TKL.csv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]
2022-02-20 Library paths changed to relative paths
    [Numpad.kicad_pcb, Numpad.kicad_sch]
2022-02-21 changed numpad mounting hole size to M2
    [Numpad.kicad_pcb, Numpad.kicad_sch]
2022-02-21 New number gerber files
    [BOM-Numpad.csv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]
2022-02-21 Redid PCB borders to be uniform between the numpad and tkl board
    [BOM-Numpad.csv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]
2022-02-21 Moved pins on numpad
    [BOM-Numpad.csv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]
2022-02-21 Fixed alignment of the TKL mounting plate template. Set TKL library path to be relative
2022-02-21 Added numpad mounting plate (and adjusted mounting hole locations)
    [BOM-Numpad.csv, BOM-plate.csv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]
2022-03-14 Updated readme and silkscreens
    [Numpad.kicad_pcb, plate.kicad_pcb]
2022-04-11 Updated pcb to fix minor interferance issue. Generated new plate as stabilizers did not fit using the old one.
    [BOM-Numpad.csv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]
